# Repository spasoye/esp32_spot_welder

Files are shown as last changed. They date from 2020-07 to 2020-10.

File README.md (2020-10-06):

# ESP spot welder control

MOT spot welder controller based on ESP32 microcontroller.

Basically it is configurable pulse generator. 
User can configure pulse's ON and OFF time and number of pulses that will be generated when the switch is pressed.
Solid state relay is then switched on and off

User interface is implemented using rotary encoder and [16x2 LCD display](https://github.com/DavidAntliff/esp32-i2c-lcd1602).

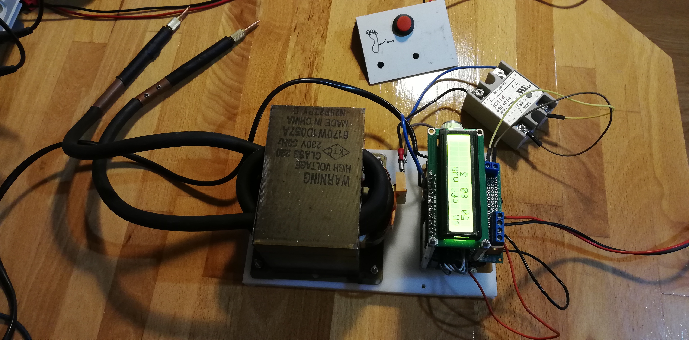
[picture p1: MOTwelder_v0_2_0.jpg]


## Build and flash
```bash
git clone git@github.com:spasoye/esp32_spot_welder.git
```

Build using make:
```bash
cd esp32_spot_welder/firmware
make all -j 8
make flash
```

Build usin *idf.py* tool:
```bash
idf.py build flash
```

## Links
https://github.com/DavidAntliff/esp32-i2c-lcd1602

## Status

Active

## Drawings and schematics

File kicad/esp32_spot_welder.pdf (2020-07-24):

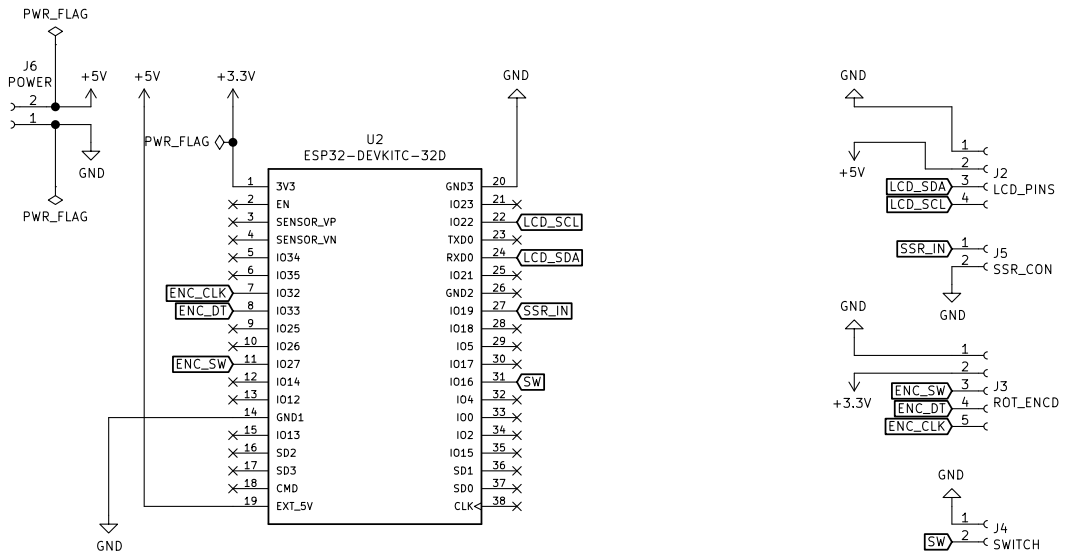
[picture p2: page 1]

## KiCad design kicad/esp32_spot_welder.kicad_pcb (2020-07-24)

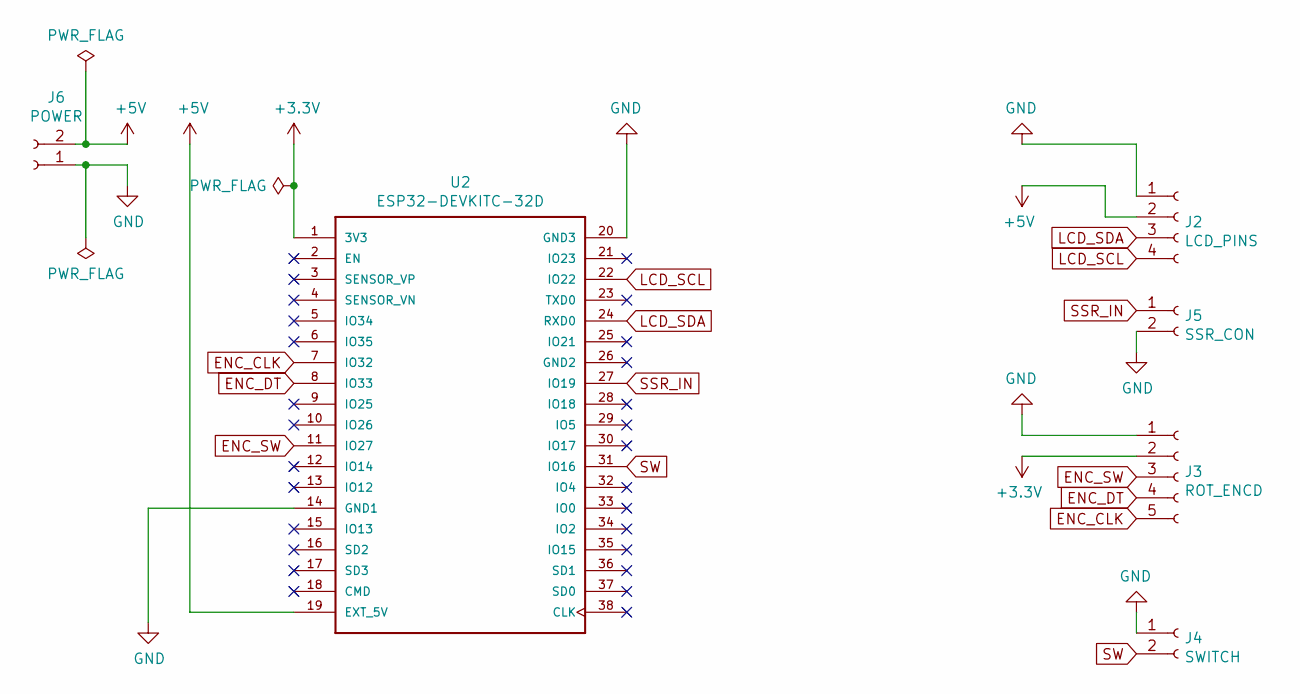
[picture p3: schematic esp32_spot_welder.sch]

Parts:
J2: LCD_PINS; PinHeader_1x04_P2.00mm_Vertical
J3: ROT_ENCD; PinHeader_1x05_P2.00mm_Vertical
J4: SWITCH; TerminalBlock_Philmore_TB132_1x02_P5.00mm_Horizontal
J5: SSR_CON; TerminalBlock_Philmore_TB132_1x02_P5.00mm_Horizontal
J6: POWER; TerminalBlock_Philmore_TB132_1x02_P5.00mm_Horizontal
U2: ESP32-DEVKITC-32D; MODULE_ESP32-DEVKITC-32D

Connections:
+3V3: J3.2, U2.1 (3V3)
+5V: J2.2, J6.2, U2.19 (EXT_5V)
ENC_CLK: J3.5, U2.7 (IO32)
ENC_DT: J3.4, U2.8 (IO33)
ENC_SW: J3.3, U2.11 (IO27)
GND: J2.1, J3.1, J4.1, J5.2, J6.1, U2.14 (GND1), U2.20 (GND3)
LCD_SCL: J2.4, U2.22 (IO22)
LCD_SDA: J2.3, U2.24 (RXD0)
SSR_IN: J5.1, U2.27 (IO19)
SW: J4.2, U2.31 (IO16)

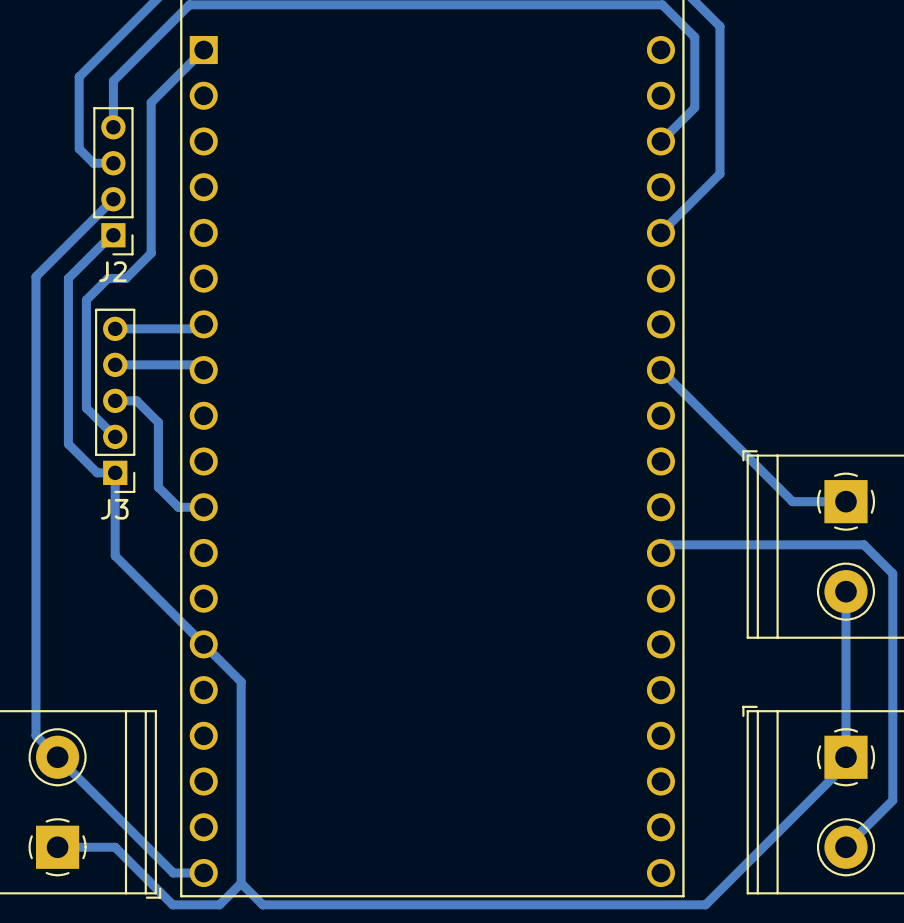
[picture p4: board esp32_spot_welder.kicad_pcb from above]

Board: 2 copper layers, 6 parts (0 on the bottom side), 10 nets.

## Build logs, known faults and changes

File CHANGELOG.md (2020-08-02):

# Changelog

## Unreleased

## [v0.1.0] - 2020-11-05
### Added
- First release. Device prototype.
- Added LCD1602 screen and [software interface](https://github.com/DavidAntliff/esp32-i2c-lcd1602) to control the screen.
- Added rotary encoder and implemented interface for it.
- Mechanical relay control.

## [v0.2.0] - 2020-08-02
### Added
- User can now change on and off duration and number of pulses.
- Implemented multiple properties interface.
  
### Changed
- Replaced 12V supply and 7805  with 5V supply.
- Replaced mechanical relay with solid state relay.

### Fixed
- Fixed rotary encoder and switch debounce issues.
- Project folder structure cleanup

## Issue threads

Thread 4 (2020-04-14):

encoder debounce issue

spasoye, 2020-04-14:

Closed 2020-07-24.

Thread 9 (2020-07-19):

bug when interrupt happens

spasoye, 2020-07-19:
I get:

```bash
Guru Meditation Error: Core  0 panic'ed (Interrupt wdt timeout on CPU0).
```

spasoye, 2020-07-19:
Happens when turning encoder very slowly

Closed 2020-07-21.

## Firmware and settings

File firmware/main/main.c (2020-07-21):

#include <stdio.h>
#include "freertos/FreeRTOS.h"
#include "freertos/task.h"
#include <freertos/semphr.h>

#include <driver/gpio.h>

#include <lcd.h>
#include <interface.h>
#include <control.h>

void app_main(void)
{
    lcd_init();

    interface_init();
    control_init();

    while (1) {
        vTaskDelay(portMAX_DELAY);
    }
}

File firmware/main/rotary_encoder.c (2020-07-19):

#include <math.h>
#include <driver/gpio.h>
#include "freertos/FreeRTOS.h"
#include "freertos/task.h"
#include "freertos/queue.h"
#include "rotary_encoder.h"

#include "lcd.h"

#define ENC_CLK     GPIO_NUM_32
#define ENC_DT      GPIO_NUM_33
#define ENC_SW      GPIO_NUM_27

static QueueHandle_t p_encoder_queue = NULL;
static int16_t duration = 100;
static uint16_t click_debounce = 200;
static uint16_t rot_debounce = 10;

static uint8_t warning1 = 150;
static uint8_t warning2 = 500;
static uint8_t warning3 = 1000;

/**
 * @brief  Rotary encoder interrupt service routine. 
 * @note   Debounce protocol should be done here.
 * @param  *arg: pin that triggered the interrupt.
 * @retval None
 */
static void IRAM_ATTR encoder_isr_handler(void *arg);

static void IRAM_ATTR click_isr_handler(void *arg);

/**
 * @brief  Task routine that haqndles interrupt events.
 * @note   None.
 * @param  *arg: task arguments. None in this case.
 * @retval None
 */
static void rotary_encoder_task(void *arg);

uint8_t rotary_encoder_init(void)
{
    gpio_config_t io_conf;
    uint8_t ret = 1;

    // Getting better results when level triggering
    io_conf.intr_type = GPIO_PIN_INTR_LOLEVEL;
    io_conf.mode = GPIO_MODE_INPUT;
    io_conf.pin_bit_mask = (1ULL<<ENC_CLK);
    io_conf.pull_down_en = GPIO_PULLDOWN_DISABLE;
    io_conf.pull_up_en = GPIO_PULLDOWN_DISABLE;
    gpio_config(&io_conf);

    io_conf.intr_type = GPIO_PIN_INTR_DISABLE;
    io_conf.pin_bit_mask = (1ULL<<ENC_DT);
    io_conf.mode = GPIO_MODE_INPUT;
    io_conf.pull_up_en = GPIO_PULLDOWN_DISABLE;
    io_conf.pull_down_en = GPIO_PULLDOWN_DISABLE;
    gpio_config(&io_conf);

    io_conf.intr_type = GPIO_PIN_INTR_NEGEDGE;
    io_conf.pin_bit_mask = (1<<ENC_SW);
    io_conf.mode = GPIO_MODE_INPUT;
    io_conf.pull_up_en = GPIO_PULLDOWN_DISABLE;
    io_conf.pull_down_en = GPIO_PULLDOWN_DISABLE;
    gpio_config(&io_conf);

    gpio_install_isr_service(0);

    gpio_isr_handler_add(ENC_CLK, encoder_isr_handler, (void*)ENC_CLK);
    gpio_isr_handler_add(ENC_SW, click_isr_handler, (void*)ENC_SW);

    p_encoder_queue = xQueueCreate(1, sizeof(encoder_event_t));

    ret = (pdPASS ==xTaskCreate(rotary_encoder_task, "rotary_encoder_task", 2048, NULL, 10, NULL)) ? 0 : 1;

    return ret;
}

void rotary_encoder_int_disable(void)
{
    gpio_intr_disable(ENC_CLK);
}

void rotary_encoder_int_enable(void)
{
    gpio_intr_enable(ENC_CLK);
}

static void rotary_encoder_task(void *arg)
{
    encoder_event_t encod_val;
    uint8_t digit_pos = 0;
    uint8_t cursor_pos[] = {4, 1};

    lcd_set_dur(duration);
    lcd_user_pointer(cursor_pos);

    while(true)
    {
        if (xQueueReceive(p_encoder_queue, &encod_val, portMAX_DELAY))
        {
            rotary_encoder_int_enable();

            printf("Interrupt from %d\n", encod_val);
            switch (encod_val)
            {
            case CLICK:
                digit_pos = (digit_pos+1)%4;
                cursor_pos[0] = 4-digit_pos;
                printf("Digit: %d\n", digit_pos);
                lcd_user_pointer(cursor_pos);
                break;

            case CCW:
                printf("-\n");
                duration = duration - pow(10, digit_pos);
                break;

            case CW:
                printf("+\n");
                duration = duration + pow(10, digit_pos);
                break;

            default:
                break;
            }
            
            // Value can't be smaller than 0;
            if (duration < 0)
            {
                duration = 0;
            }

            // Value can't be larger than 5000 ms.
            if (duration > 5000)
            {
                duration = 5000;
            }

            // Signal the user if the duration is to long.
            if (0 <= duration && warning1 >= duration)
            {
                lcd_set_warning(0);
            }
            else if (warning1 < duration && warning2 >= duration)
            {
                lcd_set_warning(1);
            }
            else if ((warning2 < duration && 1000 >= duration))
            {
                lcd_set_warning(2);
            }
            else
            {
                lcd_set_warning(3);
            }

            lcd_set_dur(duration);
        }
    }
}

uint16_t rotary_encoder_get_duration(void)
{
    return duration;
}

static void IRAM_ATTR encoder_isr_handler(void *arg)
{
    static uint32_t last_ms = 0;
    uint32_t cur_ms = xTaskGetTickCountFromISR();
    encoder_event_t val;

    if (rot_debounce < ((cur_ms - last_ms) * portTICK_PERIOD_MS))
    {
        uint8_t a = gpio_get_level(ENC_CLK);
        uint8_t b = gpio_get_level(ENC_DT);
        
        if (a == b)
        {
            val = CCW;
        }
        else
        {
            val = CW;
        }

        // Disable interrupts until the handling is done.
        gpio_intr_disable(ENC_CLK);
        
        xQueueSendFromISR(p_encoder_queue, &val, NULL);
    }

    last_ms = cur_ms;
}

static void IRAM_ATTR click_isr_handler(void *arg)
{
    static uint32_t last_ms = 0;
    uint32_t cur_ms = xTaskGetTickCountFromISR();
    encoder_event_t val = CLICK;

    if (click_debounce < ((cur_ms - last_ms) * portTICK_PERIOD_MS))
    {
        xQueueSendFromISR(p_encoder_queue, &val, NULL);
    }

    last_ms = cur_ms;
}

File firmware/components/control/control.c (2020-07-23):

#include <control.h>
#include "freertos/FreeRTOS.h"
#include "freertos/task.h"
#include <freertos/semphr.h>
#include <driver/gpio.h>
#include "lcd.h"
#include "interface.h"

#define MOT_CTRL_GPIO   18
#define SWITCH_GPIO     16

static SemaphoreHandle_t input_semph = NULL;

// TODO: comment this
static void control_task(void* arg);
static void IRAM_ATTR gpio_isr_handler(void* arg);
static void control_pulse(uint16_t on_time, uint16_t off_time, uint8_t num);

void control_init(void)
{
    gpio_config_t io_conf;

    io_conf.intr_type = GPIO_PIN_INTR_DISABLE;
    io_conf.mode = GPIO_MODE_OUTPUT;
    io_conf.pin_bit_mask = (1<<MOT_CTRL_GPIO);
    io_conf.pull_down_en = GPIO_PULLDOWN_ENABLE;
    io_conf.pull_up_en = GPIO_PULLDOWN_DISABLE;
    gpio_config(&io_conf);

    io_conf.intr_type = GPIO_PIN_INTR_NEGEDGE;
    io_conf.pin_bit_mask = 1<<SWITCH_GPIO;
    io_conf.mode = GPIO_MODE_INPUT;
    io_conf.pull_up_en = GPIO_PULLDOWN_DISABLE;
    io_conf.pull_down_en = GPIO_PULLDOWN_DISABLE;
    gpio_config(&io_conf);

    input_semph = xSemaphoreCreateBinary();
    xTaskCreate(control_task, "control_task", 2048, NULL, 10, NULL);

    gpio_install_isr_service(0);
    gpio_isr_handler_add(SWITCH_GPIO, gpio_isr_handler, (void*)SWITCH_GPIO);
}

static void control_task(void* arg)
{
    uint16_t on_time;
    uint16_t off_time;
    uint16_t pulses;

    for(;;) {
        if(xSemaphoreTake(input_semph, portMAX_DELAY)) {
            printf("Switch pressed\n");
            gpio_intr_disable(SWITCH_GPIO);

            printf("ON: %d\n", on_time);
            printf("OFF: %d\n", off_time);
            printf("NUM: %d\n", pulses);
            
            interface_get_val(&on_time, &off_time, &pulses);

            printf("ON: %d\n", on_time);
            printf("OFF: %d\n", off_time);
            printf("NUM: %d\n", pulses);

            control_pulse(on_time, off_time, pulses);
            
            vTaskDelay(500/portTICK_PERIOD_MS);

            gpio_intr_enable(SWITCH_GPIO);
        }
    }
}

static void control_pulse(uint16_t on_time, uint16_t off_time, uint8_t num)
{
    gpio_set_level(MOT_CTRL_GPIO, 0u);

    for(uint8_t cnt=0; cnt < num; cnt++)
    {
        printf("pulse %d \n", cnt);

        gpio_set_level(MOT_CTRL_GPIO, 1u);
        vTaskDelay(on_time/portTICK_PERIOD_MS);
        gpio_set_level(MOT_CTRL_GPIO, 0u);
        vTaskDelay(off_time/portTICK_PERIOD_MS);
    }

    gpio_set_level(MOT_CTRL_GPIO, 0u);
}

static void IRAM_ATTR gpio_isr_handler(void* arg)
{
    // TODO: debounce handle
    // Signal the GPIO task.
    xSemaphoreGiveFromISR(input_semph, NULL);
}

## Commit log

2020-03-18 Interrupt on falling edge
2020-03-28 Added esp32-smbus DavidAntliff repo as submodule
2020-03-28 Added esp32-i2c-lcd1602 David's repo as submodule
2020-04-02 Rotary encoder WIP
2020-04-03 Implemented rotary encoder WIP
2020-04-04 Fixed encoder triggering
2020-04-04 Changing the duration value using encoder
2020-04-08 Implemented rotart encoder interrupt disable/enable functions
2020-04-12 fixing debounce issue WIP
    [rotary_encoder.c]
2020-04-12 Added sch and pcb
    [esp32_spot_welder.kicad_pcb, esp32_spot_welder.sch]
2020-04-18 kicad fix
2020-06-27 kicad changes
2020-07-02 separeted firmware and pcb
2020-07-14 kicad stuff to gitignore
2020-07-14 kicad changed
    [esp32_spot_welder.kicad_pcb, esp32_spot_welder.sch]
2020-07-20 Switch and MOT ctrl to separate component
2020-07-21 Implemented short and long press
    [interface.c]
2020-07-24 fixed rot_encd debounce issue
    [interface.c]
2020-07-24 updated kicad
    [esp32_spot_welder.kicad_pcb, esp32_spot_welder.sch]
2026-02-02 Revise README.md for clarity and detail on ESP32 DIY Spot Welder features, usage, and safety warnings
